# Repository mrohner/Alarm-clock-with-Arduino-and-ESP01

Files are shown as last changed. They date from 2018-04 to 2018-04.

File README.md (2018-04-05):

# Alarm clock
Alarm clock that gets system time from my server. Not only it measures temperature and humidity in my bedroom, but also 
checks for movements. In the night, because my eye sight is not too good, the time is displayed by a Neopixel ring. You can set
an alarm to wake you in the morning. I use an Arduino Nano to do all the IO's and an ESP01 for communicating through
the wifi network. You may also use a Wemos D1 mini instead but I like to use up my Nanos and ESP01s for that purpose.
See also the PCB Board in Eagle I developped for this project.

OK, it does not look very exciting but there are a lot of topics that are covered with this project, such as:
* Communication between Arduino Nano and ESP01 through Json
* Displaying time with a Neopixel ring
* Using MQTT to request time from the server
* Using node-red to extract time from the server and make it available to my home automation nodes

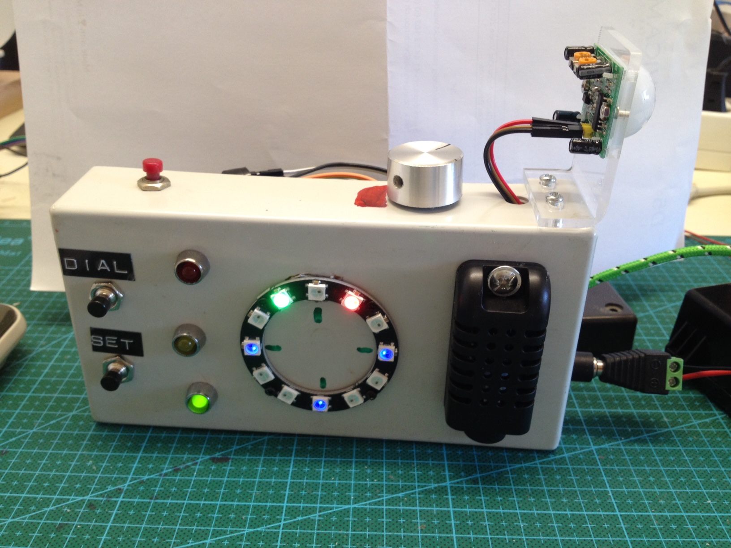
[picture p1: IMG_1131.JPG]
Alarm Clock


It is one o'clock and 55 minutes.

## How It Works
- when the clock starts up the ESP01 requests the system time from the server through MQTT and Node-red
- The ESP01 also communicates the temperature and humidity as well as movements to MQTT and ultimately to Domoticz
- The Arduino Nano does all the IO's, drives the Neopixels and reports to the ESP01 via json
- Press the Set switch to set the alarm, press the dial switch to change alarm time, press the panic switch to display time
  and to snooze when alarm goes off.
- The time is displayed like the hour beeing a red and the minutes beeing a green LED on the Neopixel ring.

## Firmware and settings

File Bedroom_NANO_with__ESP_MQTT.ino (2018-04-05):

/*
 alarm clock by Markus Rohner
 Version 1.0     1.Apr.2018
 
 Funtion: Alarm clock and Movement detection. Buzzer serves as house alarm
  
 Aknowledgements:
 1. Adafruit Neopixel library: http://learn.adafruit.com/adafruit-neopixel-uberguide/neomatrix-library
                       
NANO Pins:
 D0: (RX) ESP8266 TX
 D1: (TX) ESP8266 RX 3.3V!
 D5: green LED  not used                                                                              
 D6: Yellow LED not used
 D7: Red LED wake_up call set
 D9: Neopixel dataline + over 200Ohm resistor   should be 330Ohm though
 D10: buzzer + over 100Ohm resistor (needs to be on pin D10)
 D11: Softserial RX to FTDI
 D12: Softserial TX to FTDI  
 D14(A0): Dial Switch  
 D15(A1): Set Switch
 D16(A2): Panic Switch 
 A3: Potentiometer to set brightness of Neopixel 
 D18(A4): PIR Movement     
 D19(A5): DHT sensor
  
 Bill of material:
 - Power Supply Converter AC 100-240V to DC 5V 1A Switching
   (all devices powered directly from the 5V power supply, not by the arduino)
 - Arduino Nano
 - Nice box
 - 3 x Push button (10k resistor to GND)
 - 3 x 10K Ohm resistor for switches
 - 1 x WS2811 WS2812 5050 RGB LED Light ring Individually Addressable DC5V 
 - 1 x 1000uF 16V 10x16mm Radial Capacitor Electrolytic to protect RGB LEDs
 - 1 x Resisor 330 Ohm for RGB LEDs data line
 - 1 buzzer
 - 1 x resistor 100 Ohm for Buzzer
 - 1ea. 5mm LEDs green, yellow, red
 - 3 x 330 Ohm for LEDs
 - cables etc.
 */
#include <TimeLib.h>
#include <SimpleTimer.h>
#include <ArduinoJson.h>
#include <SoftwareSerial.h>
SoftwareSerial MySerial(11,12); // RX, TX attached to a FTDI adapter

#include "DHT.h"
#define DHTPIN 19     // what pin we're connected to
#define DHTTYPE DHT21 // AM2301  
DHT dht(DHTPIN, DHTTYPE);

// RGB Lights
#include <Adafruit_NeoPixel.h>
#define NUM_BUTTONS  12    
#define PIN 9         // Signal Pin
const int long red = 16711680;
const int long green = 45568;//was 65280
const int long blue = 255;
int brightness = map(analogRead(A3),0,1023,0,255);
Adafruit_NeoPixel strip = Adafruit_NeoPixel(NUM_BUTTONS, PIN, NEO_GRB + NEO_KHZ800);
// IMPORTANT: To reduce NeoPixel burnout risk, add 1000 uF capacitor across
// pixel power leads, add 300 - 500 Ohm resistor on first pixel's data input
// and minimize distance between Arduino and first pixel.  Avoid connecting
// on a live circuit...if you must, connect GND first.

int hours, minutes;
const int waiting = 600;
const byte Green_LED = 5;     // LED green
const byte PirPin = 18;       // choose the input pin (for PIR sensor)
const byte Red_LED = 7;       // LED red
const byte Yellow_LED = 6;    // Yellow LED
const byte dial_Switch = 14;  // Switch 2
const byte panic_Switch = 16; // Panic Switch
const byte set_up_Switch = 15;// Switch 1
int pressed_switch = 0;
const int display_time = 6000;// micro seconds display is on
bool movement = 0;
bool movement_on = 0;
float h = 0;
float t = 0;
SimpleTimer timer;
int movetimer = -1;
int snoozetimer = -1;

// Buzzer
// TONES  ==========================================
// Start by defining the relationship between 
//       note, period, &  frequency. 
#define  cc     3830    // 261 Hz 
#define  dd     3400    // 294 Hz 
#define  ee     3038    // 329 Hz 
#define  ff     2864    // 349 Hz 
#define  gg     2550    // 392 Hz 
#define  aa     2272    // 440 Hz 
#define  bb     2028    // 493 Hz 
#define  CC     1912    // 523 Hz 
// Define a special note, 'R', to represent a rest
#define  RR     0
bool alarm = LOW;
bool snooze = LOW;
int speakerOut = 10;
// MELODY and TIMING  =======================================
//  melody[] is an array of notes, accompanied by beats[], 
//  which sets each note's relative length (higher #, longer note) 
int melody[] = {  CC,  bb,  gg,  CC,  bb,   ee,  RR,  CC,  cc,  gg, aa, CC };
int beats[]  = { 16, 16, 16,  8,  8,  16, 32, 16, 16, 16, 8, 8 }; 
int MAX_COUNT = sizeof(melody) / 2; // Melody length, for looping.

// Set overall tempo
long tempo = 10000;
// Set length of pause between notes
int pause = 1000;
// Loop variable to increase Rest length
int rest_count = 100; //<-BLETCHEROUS HACK; See NOTES

// Initialize core variables
int tone_ = 0;
int beat = 0;
long duration  = 0;

//EEPROM
#include <EEPROM.h>
struct MyObject {
  byte wake_hour;
  byte wake_minute;
  byte onoff;
  };
MyObject wakeup;


void setup() {
  Serial.begin(115200);
  MySerial.begin(19200);
  dht.begin();
  timer.setInterval(120000L,checkDHT);//2 mins
  checkDHT();
  pinMode(PirPin, INPUT);
  pinMode(speakerOut, OUTPUT);  
  pinMode (dial_Switch, INPUT);
  pinMode (set_up_Switch, INPUT);
  pinMode (panic_Switch, INPUT);
  pinMode (Green_LED, OUTPUT);
  digitalWrite(Green_LED, LOW);
  pinMode (Red_LED, OUTPUT);
  digitalWrite(Red_LED, LOW);
  pinMode (Yellow_LED, OUTPUT);
  digitalWrite(Yellow_LED, LOW);

  strip.begin();
  strip.show(); // Initialize all pixels to 'off'
  for (int y = 0; y < 4; y++) {
    blue_circle();
  }

  EEPROM.get(0, wakeup);
  if (wakeup.onoff) { //Alarm clock is set
    digitalWrite(Red_LED, HIGH);
    }
  MySerial.println();
  MySerial.println(F("Alarm data:"));
  MySerial.print(wakeup.wake_hour);
  MySerial.print(":");
  if (wakeup.wake_minute < 10) MySerial.print("0");
  MySerial.print(wakeup.wake_minute);
  MySerial.print(" ");
  if (wakeup.onoff == 0) MySerial.println("Off");
  else MySerial.println("On");
  delay(60000);
  requestTimefromESP();
  while (!Serial) {
    } //wait for the ESP to connect
  timer.setInterval(1000L,toggle_Yellow_LED);//1 sec 
  timer.setInterval(600000L,check_time_is_set);//10 min  
}


void loop() {
  getRequestFromESP();
  if (timeStatus() == timeSet) digitalWrite(Green_LED, HIGH);
  else digitalWrite(Green_LED, LOW);
  timer.run(); // Initiates SimpleTimer
  movement = digitalRead(PirPin);
  if (movement && !movement_on) {
    MySerial.println(F("Move detected"));
    movement_on = 1;
    sendUpdateToESP();
    movetimer = timer.setTimeout(600000, resetmove);//10 mins
    }
  if (digitalRead(panic_Switch) && alarm) {
    timer.disable(snoozetimer);
    snoozetimer = timer.setTimeout(360000, resetsnooze);//6 mins
    snooze = HIGH;
    alarm = LOW;
    MySerial.println(F("panic_Switch pressed"));
    pressed_switch = 1;
    }
  else if (digitalRead(panic_Switch)) {
    pressed_switch = 1;
    MySerial.println(F("panic_Switch pressed"));
    }  
  if (digitalRead(set_up_Switch)) {
    MySerial.println(F("set_up_Switch pressed"));
    wake_time();
    } 
  if ((alarm || (wakeup.onoff && ((wakeup.wake_hour == hour()) || ((wakeup.wake_hour + 12) == hour())) && (wakeup.wake_minute == minute())))&& !snooze) {
    alarm = HIGH;
    show_time();
    sound_Alarm();
    }
  if (pressed_switch == 1) show_time();
}


void show_time (){
  int neo_hour = hour();
  if (neo_hour >= 12) neo_hour = neo_hour - 12;
  int neo_minutes = minute() / 5;
  for (int x = 0; x < NUM_BUTTONS; x++) {
    uint32_t newcolor = 0;
    if (x == 0 || x == 6 || x == 3 || x == 9) newcolor = 20;
    if (neo_hour == x) newcolor = newcolor + red;
    if (neo_minutes == x) newcolor = newcolor + green;
  strip.setPixelColor(x,newcolor);
  waitandbright(15);
  }
  if (!alarm){
    waitandbright(display_time);
    blue_circle();
    blue_circle();
    pressed_switch = 0;
  }
}

 
void wake_time() {
  int neo_hour = wakeup.wake_hour;
  if (neo_hour >= 12) neo_hour = neo_hour - 12;
  int neo_minutes = wakeup.wake_minute / 5;
  if (neo_minutes > 11) neo_minutes = 0;
  show_waketime (neo_hour,neo_minutes);
  MySerial.println(F("Set wake time"));
  while (digitalRead(set_up_Switch) == LOW) {
    if (digitalRead(dial_Switch)) {
      neo_minutes++;
      if (neo_minutes == 12) {
        neo_minutes = 0;
        neo_hour++;
        if (neo_hour == 12) neo_hour = 0;
      }
      show_waketime (neo_hour,neo_minutes);
    }
  }
    
  neo_minutes = 5 * neo_minutes;
  wakeup.onoff = 1;
  digitalWrite(Red_LED,wakeup.onoff);
  waitandbright(waiting);
  MySerial.println(F("Set alarm on/off"));
  while (digitalRead(set_up_Switch) == LOW) {
     if (digitalRead(dial_Switch)) {
       wakeup.onoff = !wakeup.onoff;
       digitalWrite(Red_LED,wakeup.onoff);
       alarm = LOW;
       snooze = LOW;
       timer.disable(snoozetimer);
       waitandbright(waiting);
      }
    }
  while (digitalRead(set_up_Switch) == LOW) {
    } 
  MySerial.println(F("Write to EEPROM"));  
  wakeup.wake_hour = neo_hour;
  wakeup.wake_minute = neo_minutes;
  EEPROM.put(0, wakeup);
  wait(waiting);
  blue_circle();
 }


void show_waketime (int hour_position, int minute_position){
  for (int x = 0; x < NUM_BUTTONS; x++) {
    uint32_t newcolor = 0;
    if (x == 0 || x == 6 || x == 3 || x == 9) newcolor = 20;
    if (hour_position == x) newcolor = newcolor + red;
    if (minute_position == x) newcolor = newcolor + green;
  strip.setPixelColor(x,newcolor);
  waitandbright(15);
  }
}


void blue_circle() {
  for (int x = 0; x < NUM_BUTTONS; x++) {
    strip.setPixelColor(x,0);
  }
  strip.show();
  for (int x = 0; x < NUM_BUTTONS; x++) {
    strip.setPixelColor(x, blue); // bright blue color.
    waitandbright(20);
    strip.setPixelColor(x,0);
    waitandbright(20);
  } 
}


void sound_Alarm() {
  MySerial.println(F("Alarm Sound"));

  // Set up a counter to pull from melody[] and beats[]
  for (int i=0; i<MAX_COUNT; i++) {
    tone_ = melody[i];
    beat = beats[i];
    duration = beat * tempo; // Set up timing
    if (digitalRead(panic_Switch) && alarm) return;
    playTone(); 
    // A pause between notes...
    delayMicroseconds(pause);
  }
 }


// PLAY TONE  ==============================================
// Pulse the speaker to play a tone for a particular duration
void playTone() {
  long elapsed_time = 0;
  if (tone_ > 0) { // if this isn't a Rest beat, while the tone has 
    //  played less long than 'duration', pulse speaker HIGH and LOW
    while (elapsed_time < duration) {

      digitalWrite(speakerOut,HIGH);
      delayMicroseconds(tone_ / 2);

      // DOWN
      digitalWrite(speakerOut, LOW);
      delayMicroseconds(tone_ / 2);

      // Keep track of how long we pulsed
      elapsed_time += (tone_);
    } 
  }
  else { // Rest beat; loop times delay
    for (int j = 0; j < rest_count; j++) { // See NOTE on rest_count
      delayMicroseconds(duration);  
    }                                
  }                                 
}


void wait (int d_time) {
  for (int i = 0; i <  abs((d_time / 15)); i++)delayMicroseconds(15000);
}


void waitandbright (int d_time) {
  strip.setBrightness(map(analogRead(A3),0,1023,0,255)); 
  strip.show();
  for (int i = 0; i <  abs((d_time / 15)); i++)delayMicroseconds(15000);

}


void getRequestFromESP(){
  if (Serial.available()) {    
    StaticJsonBuffer<190> jsonBuffer;
    JsonObject& root = jsonBuffer.parseObject(Serial);
    const char* command = root["command"];
    int what = root["what"];
    int h = root["h"];
    int m = root["m"];
    int s = root["s"];
    String commandString = String(command);
    if (commandString == "alarm" || commandString == "update" || commandString == "time") {
      MySerial.print(commandString);
      MySerial.print(" ");
      if (commandString == "time") {
        MySerial.print(h);
        MySerial.print(":");
        MySerial.print(m);
        MySerial.print(":");
        MySerial.print(s);
        MySerial.println("");
      }
      MySerial.println(what);
    }
    if (commandString == "alarm" && what == 1) alarm = HIGH;
    else if (commandString == "alarm" && what == 0) alarm = LOW;
    else if (commandString == "time") setTime(h,m,s,1,1,2018);
    else if (commandString == "update") sendUpdateToESP();
    commandString = "";
   }
}


void sendUpdateToESP(){
  MySerial.print("Temperature: ");
  MySerial.print(t);
  MySerial.print(" ");
  MySerial.print("Humidity: ");
  MySerial.print(h);
  MySerial.print(" ");
  MySerial.print("Move: ");
  MySerial.println(movement_on);
  
  StaticJsonBuffer<120> jsonBuffer;
  JsonObject& root = jsonBuffer.createObject();
    root["temp"] = t;
    root["hum"] = h;
    root["move"] = movement_on;
  char output[120];
  root.printTo(output,sizeof(output));
  root.printTo(Serial);
  Serial.println();
} 


void checkDHT(){
  // Read temperature as Celsius
     t = dht.readTemperature();
     h = dht.readHumidity();
}


void resetmove(){
  movement_on = 0; 
}


void resetsnooze(){
  if (wakeup.onoff){
    alarm = HIGH; 
    snooze = LOW;
  } 
}


void requestTimefromESP(){
  MySerial.println("Requesting time");
  StaticJsonBuffer<60> jsonBuffer;
  JsonObject& root = jsonBuffer.createObject();
    root["request"] = 1;
  char output[60];
  root.printTo(output,sizeof(output));
  root.printTo(Serial);
  Serial.println();
} 


void toggle_Yellow_LED() {
  if (timeStatus() == timeSet) digitalWrite(Yellow_LED,!digitalRead(Yellow_LED));
}


void check_time_is_set() {
  if (timeStatus() != timeSet)requestTimefromESP();
}

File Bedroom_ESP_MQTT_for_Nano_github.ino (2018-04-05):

/*
 It connects to an MQTT server then:
  - publishes "hello world" to the topic "outTopic" every two seconds
  - subscribes to the topic "inTopic"
*/

#include <ESP8266WiFi.h>
#include <ESP8266mDNS.h>
#include <WiFiUdp.h>
#include <ArduinoOTA.h>
#include <PubSubClient.h>
#include <ArduinoJson.h>
#include <TimeLib.h>

// Update these with values suitable for your network.
const char* ssid = "xxxxxxxxxxxx";
const char* password = "xxxxxxxxxxxxx";
const char* mqtt_server = "192.168.178.59";
const char* mqtt_username = "mqtt";
const char* mqtt_password = "xxxx";
char* InTopic = "domoticz/out"; //subscribe to topic to be notified about
char* TimeTopic = "Time"; //subscribe to topic to be notified about
char* OutTopic = "domoticz/in"; 
char* OutTopic1 = "Request/Time"; 
const int ALARM_IDX = 50;
const int DHT11_SENSOR_IDX = 48;
const int MOVEMENT_IDX = 49;
float temp;
float hum;
int movement;
int timerequest = 0;
int nvalue;
int svalue;
int alarm = 0;

WiFiClient espClient;
PubSubClient client(espClient);
int value = 0;
int counter = 0;

// Timing
volatile int WDTCount = 0;
bool SyncNecessary = true;
time_t prevDisplay = 0; // when the digital clock was displayed
time_t t;
time_t lastMsg = 0;
const int INTERVAL = 600; // 10 mins = 600

void setup() {
  Serial.begin(115200);
  setup_wifi();

  client.setServer(mqtt_server, 8883);
  client.setCallback(callback);
  
   // Port defaults to 8266
  // ArduinoOTA.setPort(8266);

  // Hostname defaults to esp8266-[ChipID]
  ArduinoOTA.setHostname("ESP75-Bedroom");

  // No authentication by default
  ArduinoOTA.setPassword((const char *)"xxxx");

  ArduinoOTA.onStart([]() {
    Serial.println("Start");
  });
  ArduinoOTA.onEnd([]() {
    Serial.println("\nEnd");
  });
  ArduinoOTA.onProgress([](unsigned int progress, unsigned int total) {
    Serial.printf("Progress: %u%%\r", (progress / (total / 100)));
  });
  ArduinoOTA.onError([](ota_error_t error) {
    Serial.printf("Error[%u]: ", error);
    if (error == OTA_AUTH_ERROR) Serial.println("Auth Failed");
    else if (error == OTA_BEGIN_ERROR) Serial.println("Begin Failed");
    else if (error == OTA_CONNECT_ERROR) Serial.println("Connect Failed");
    else if (error == OTA_RECEIVE_ERROR) Serial.println("Receive Failed");
    else if (error == OTA_END_ERROR) Serial.println("End Failed");
  });
  ArduinoOTA.begin();
}


WiFiClient WiFiclient;
const int httpPort = 8080;


void loop() {
  if (!client.connected()) reconnect();
  if (now() > (t + 82800)) setReadyForClockUpdate();
  ArduinoOTA.handle();
  client.loop();
  yield();
  WDTCount = 0;
  time_t jetzt = now();
  getResponseFromNano();
  if (jetzt - lastMsg > INTERVAL) {
    lastMsg = jetzt;
    requestfromNano("update","");
   }
}


void setup_wifi() {
  WiFi.mode(WIFI_STA); 
  delay(10);
  // We start by connecting to a WiFi network
  Serial.println();
  Serial.print("Connecting to ");
  Serial.println(ssid);

  WiFi.begin(ssid, password);

  while (WiFi.status() != WL_CONNECTED) {
    delay(500);
    Serial.print(".");
  }

  Serial.println("");
  Serial.println("WiFi connected");
  Serial.println("IP address: ");
  Serial.println(WiFi.localIP());
  delay(500);
}


void reconnect() {
  // Loop until we're reconnected
  while (!client.connected()) {
    Serial.print("Attempting MQTT connection...");
    // Attempt to connect
    if (client.connect("BedroomClient",mqtt_username,mqtt_password)) {
      Serial.println("connected");
      counter = 0;
      // Once connected, publish an announcement...
      // ... and resubscribe
      client.subscribe(InTopic);
      delay(10);
      client.subscribe(TimeTopic);
      client.publish(OutTopic1,"1");
    } else {
      Serial.print("failed, rc=");
      Serial.print(client.state());
      Serial.println(" try again in .3 seconds");
      ++counter;
      if (counter > 180) ESP.reset();
      // Wait 0.3 seconds before retrying
      ArduinoOTA.handle();
      delay(300);
    }
  }
}


void callback(char* topic, byte* payload, unsigned int length) {
  StaticJsonBuffer<500> jsonBuffer;
  //const char* json = "{\"Battery\":255,\"RSSI\":12,\"dtype\":\"Light/Switch\",\"id\":\"0001406C\",\"idx\":28,\"name\":\"testswi\",\"nvalue\":0,\"stype\":\"Switch\",\"svalue1\":\"0\",\"switchType\":\"Blinds\",\"unit\":1}";
  JsonObject& root = jsonBuffer.parseObject((char*)payload);
    int Battery = root["Battery"]; // 255
    int RSSI = root["RSSI"]; // 12
    const char* dtype = root["dtype"]; // "Light/Switch"
    const char* id = root["id"]; // "0001406C"
    int idx = root["idx"]; // 34
    const char* name = root["name"]; // "testswi"
    int nvalue = root["nvalue"]; // request: 0 = open, 1 = closed
    const char* stype = root["stype"]; // "Switch"
    const char* svalue1 = root["svalue1"]; // "0"
    const char* switchType = root["switchType"]; // "Blinds"
    int unit = root["unit"]; // 1
    int day_from_system = root["day"]; // 9
    int month_from_system = root["month"]; // 11
    int year_from_system = root["year"]; // 2017
    int hour_from_system = root["hour"]; // 16
    int minutes_from_system = root["minutes"]; // 29
    int seconds_from_system = root["seconds"]; // 26
   
    String what = String(nvalue);
    if (day_from_system && SyncNecessary || timeStatus() == timeNotSet) {
      setTime(hour_from_system,minutes_from_system,seconds_from_system,day_from_system,month_from_system,year_from_system); // alternative to above, yr is 2 or 4 digit yr
      Serial.println(F("Setting Time"));
      SyncNecessary = false;
      t = now();
      do wait(1);          // wait for clock to be at 0 secs
      while (second() != 0);
      sendTimetoNano();
      }
   if (idx == ALARM_IDX) requestfromNano("alarm",what);
}  


void getResponseFromNano(){
 if (Serial.available()){    
  StaticJsonBuffer<160> jsonBuffer;
  //const char* json = "{\"door\":0,\"CO2\":1023,\"move\":1}";
  JsonObject& root = jsonBuffer.parseObject(Serial);
  temp = root["temp"];
  hum = root["hum"];
  movement = root["move"];
  alarm = root["alarm"];
  timerequest = root["request"];
  if (timerequest) sendTimetoNano();
  else if (temp != 0) {
    publish(MOVEMENT_IDX,movement,0);
    delay(10);
    publish(DHT11_SENSOR_IDX,0,temp,hum);
    delay(10);
    //json.htm?type=command&param=udevice&idx=IDX&nvalue=LEVEL&svalue=TEXT
    //IDX = id of your device (This number can be found in the devices tab in the column "IDX")
    //Level = (0=gray, 1=green, 2=yellow, 3=orange, 4=red)
    //TEXT = Text you want to display
    //if (!alarm) publish(ALARM_IDX,0,0);
    }
  }
}


void requestfromNano(String command, String what){
  StaticJsonBuffer<60> jsonBuffer;
  JsonObject& root = jsonBuffer.createObject();
    root["command"] = command;
    root["what"] = what;
  char output[60];
  root.printTo(output,sizeof(output));
  root.printTo(Serial);
  Serial.println();
}
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
